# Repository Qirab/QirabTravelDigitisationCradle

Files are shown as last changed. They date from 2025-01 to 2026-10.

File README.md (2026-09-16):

#حامل «قِراب» المتنقل للرقمنة - QTC50
# Qirab Travel Digitisation Cradle - QTC50

يعد حامل «قِراب» المتنقل للرقمنة تصميمًا مفتوح المصدر لرقمنة المخطوطات قادر على حمل كتاب بحجم A4 بالإضافة إلى كاميرا ووحدات الإضاءة بأمان أثناء التصوير المتنقل.

The Qirab™ Travel Digitsation Cradle QTC50 is an open-source manuscript digitisation design intended to safely hold an A4 sized book, camera, and lights during travel imaging.

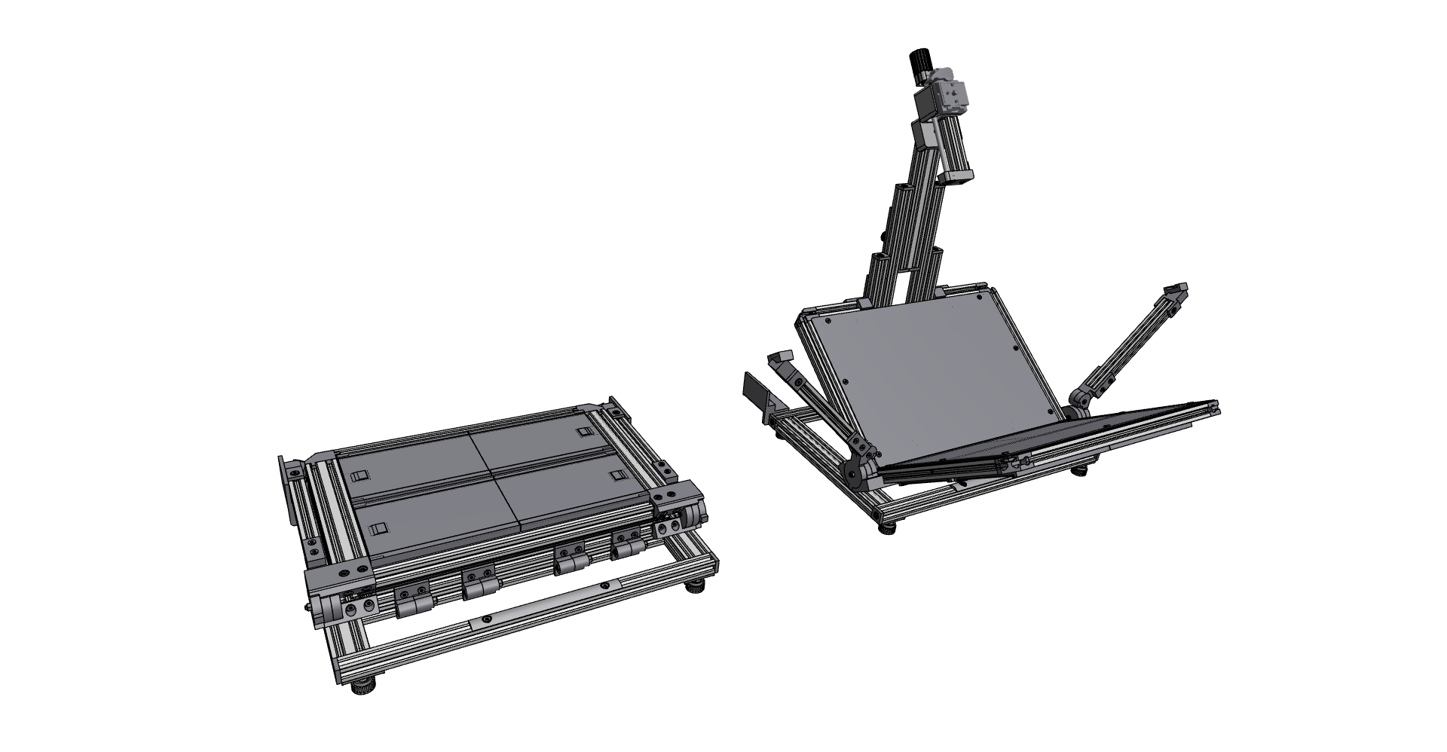
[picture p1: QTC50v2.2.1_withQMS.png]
QTC50v2.2.1_with QMS Macro Slider CAD

QTC50v2.2.1_with QMS Macro Slider CAD Drawing

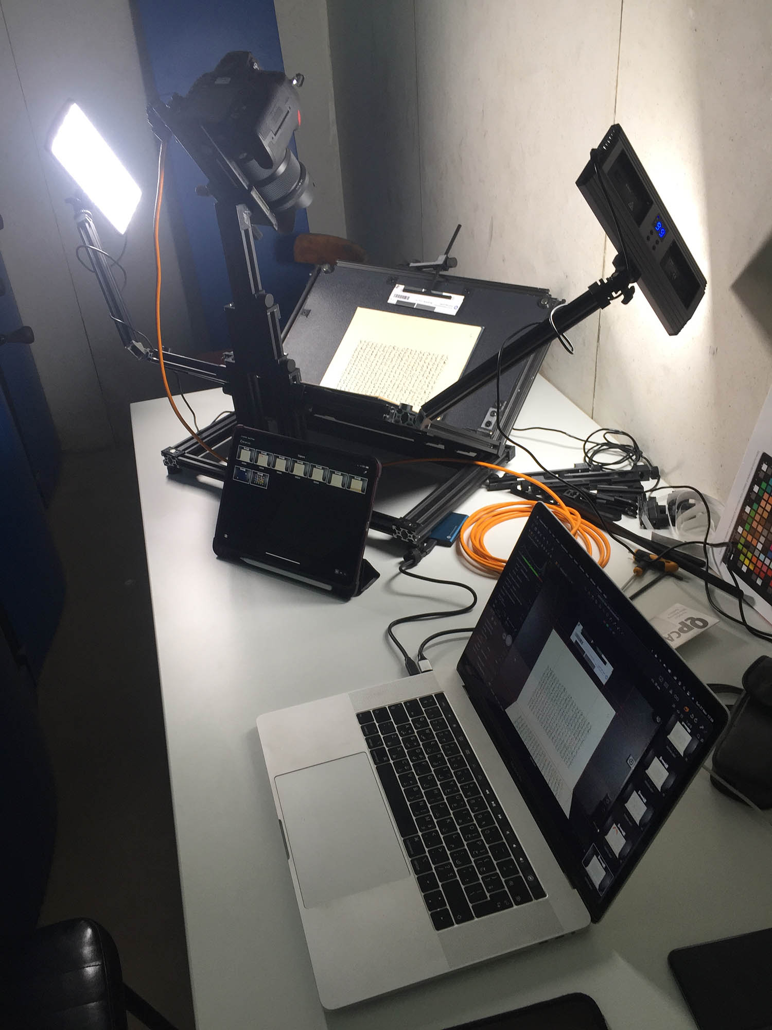
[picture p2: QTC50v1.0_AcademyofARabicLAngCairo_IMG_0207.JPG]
QTC50v1.0 Prototype testing at the Academy of Arabic Languagein Cairo, Egypt

QTC50v1.0 Prototype testing at the <a href="https://qirab.org/en/blog/2023/12/01/the-academys-manuscripts-preservation-and-digitisation/">Academy of Arabic Language in Cairo, Egypt</a>.

Requires <a href="https://github.com/Qirab/QirabTools">Qirab Tools</a> submodule.

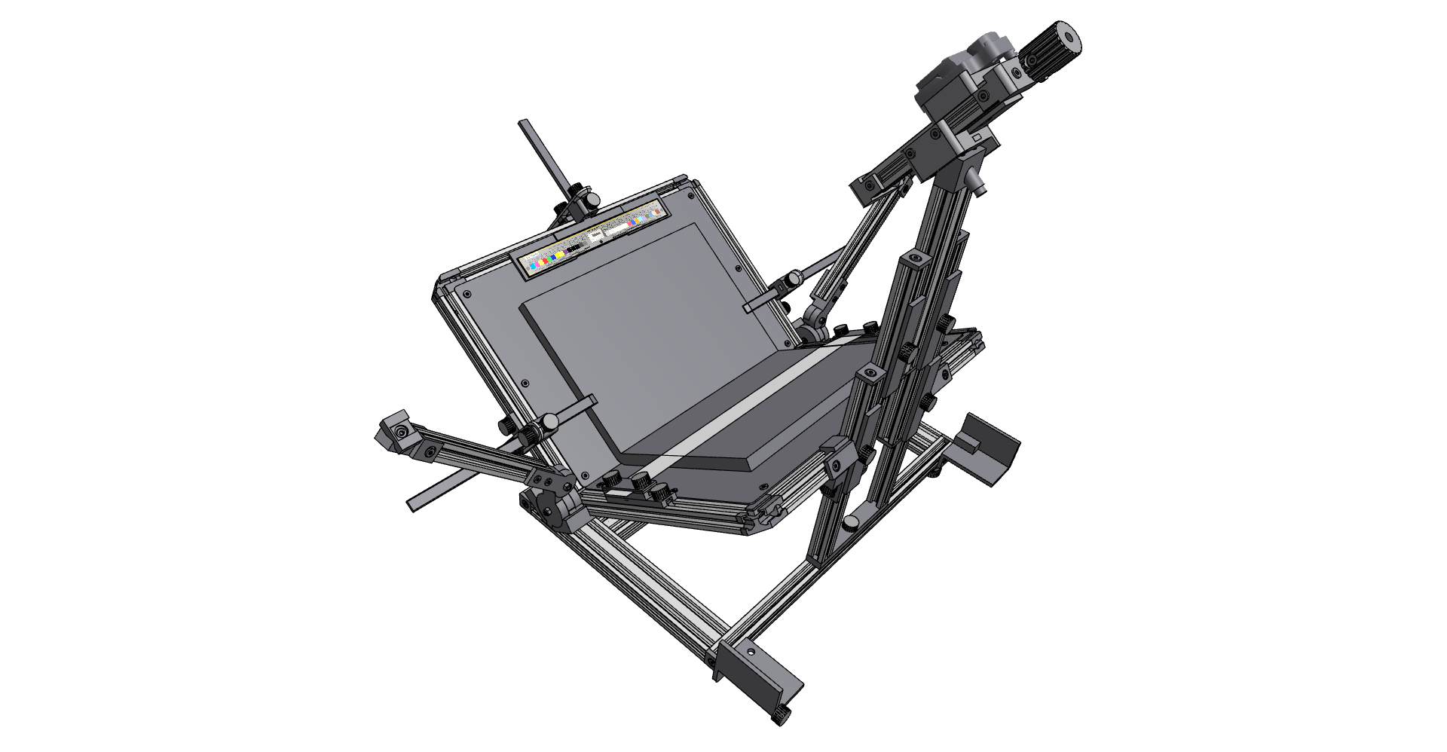
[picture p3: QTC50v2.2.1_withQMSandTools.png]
QTC50v2.2.1_with QMS Macro Slider and Qirab Tools CAD

QTC50v2.2.1_with QMS Macro Slider and Qirab Tools

<a href="https://github.com/Qirab/QirabMacroSlider">Qirab™ Macro Slider (QMS)</a> is optional.

<br />This work is licensed under a <a rel="license" href="http://creativecommons.org/licenses/by-sa/4.0/">Creative Commons Attribution-ShareAlike 4.0 International License</a>.

<br />هذا المُصنَّف مرخص بموجب <a rel="license" href="http://creativecommons.org/licenses/by-sa/4.0/">رخصة المشاع الإبداعي نَسب المُصنَّف - الترخيص بالمثل 4.0 دولي</a>.

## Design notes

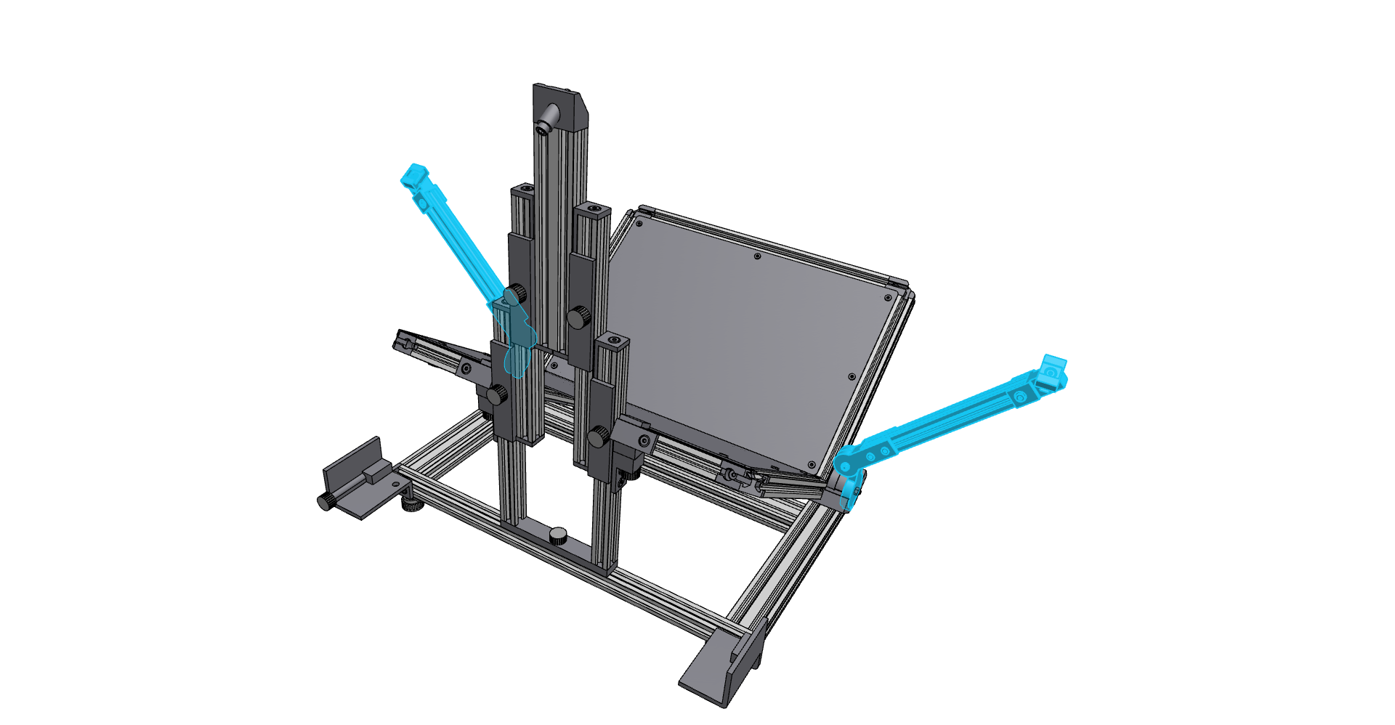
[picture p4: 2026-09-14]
PDF/Group Images/QTCv2.2.1_LightArms.png

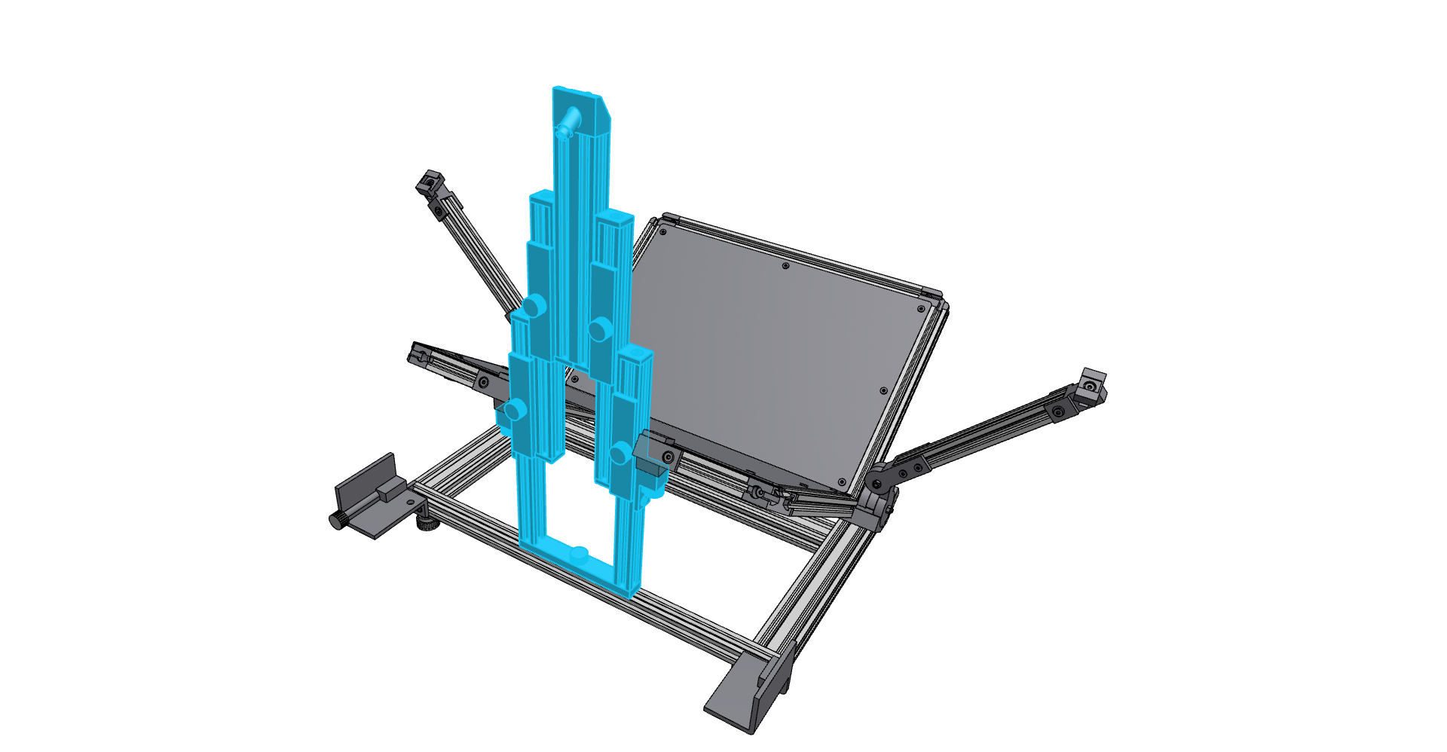
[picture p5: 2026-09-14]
PDF/Group Images/QTCv2.2.1_CameraArmSupport.png

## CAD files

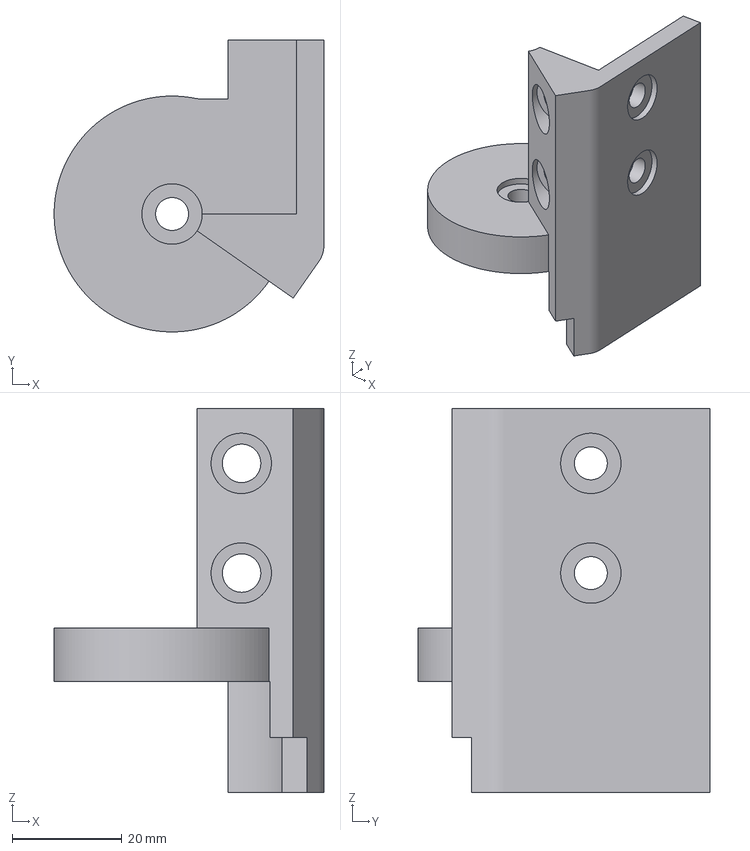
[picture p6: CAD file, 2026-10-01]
3DPRINT/1 EACH/QTC Frame Hinge Inner R.3mf
49.2 x 53.2 x 70.0 mm

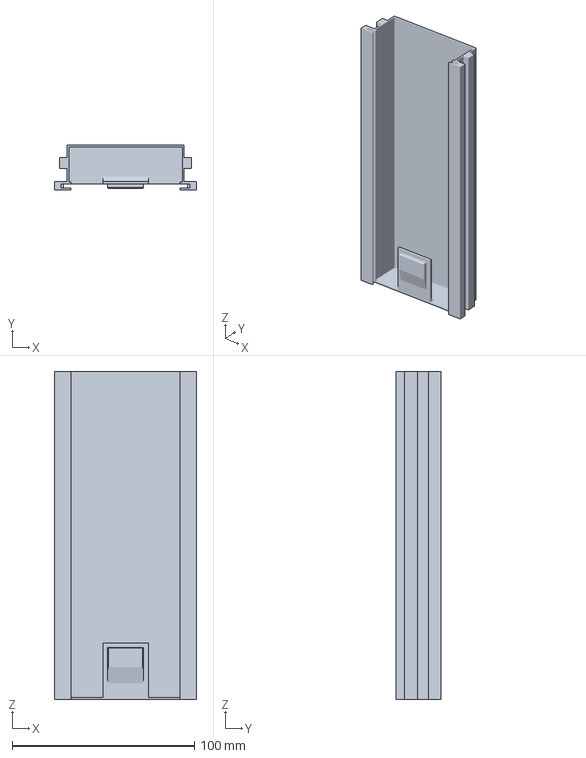
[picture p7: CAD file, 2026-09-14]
3DPRINT/2 EACH/QTC Box Small QTC50.3mf
78.0 x 24.7 x 180.0 mm

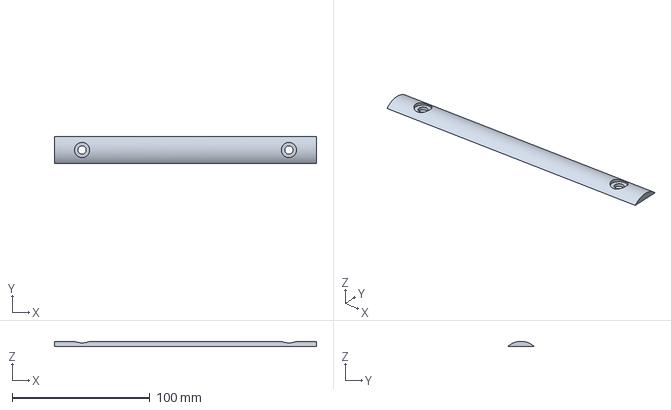
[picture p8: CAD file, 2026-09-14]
3DPRINT/3 EACH/QTC Handle Curve.3mf
190.0 x 19.3 x 3.90 mm

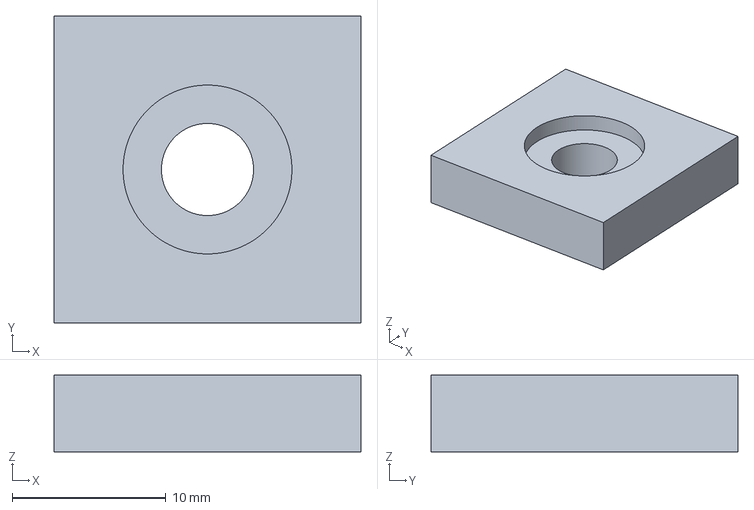
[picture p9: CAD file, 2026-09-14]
3DPRINT/4 EACH/QTC Endcap 20x20x5.3mf
20.0 x 20.0 x 5.00 mm

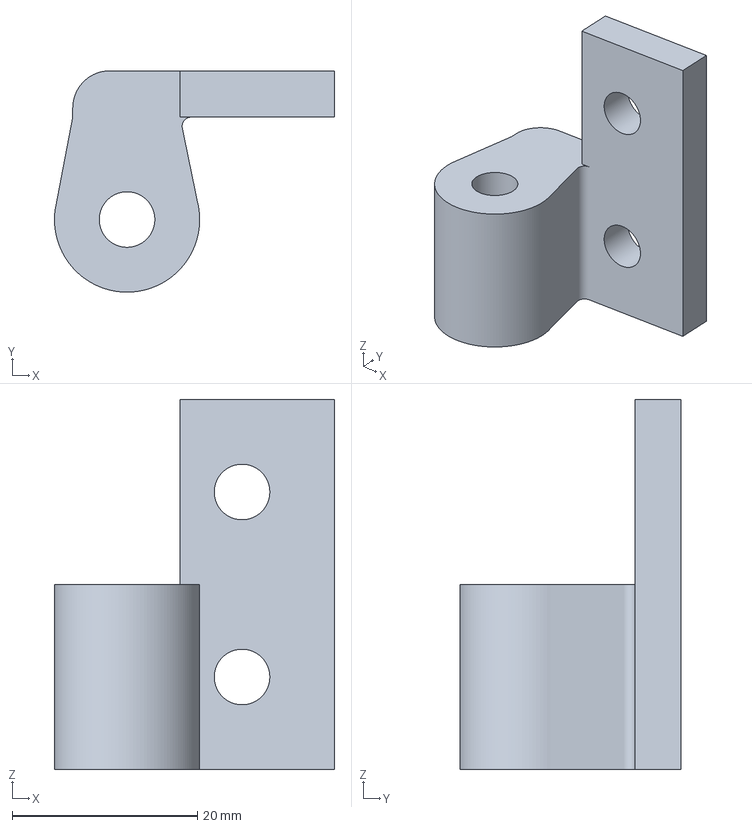
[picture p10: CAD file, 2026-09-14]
3DPRINT/8 EACH/QTC Base Hinge.3mf
30.3 x 23.9 x 40.0 mm

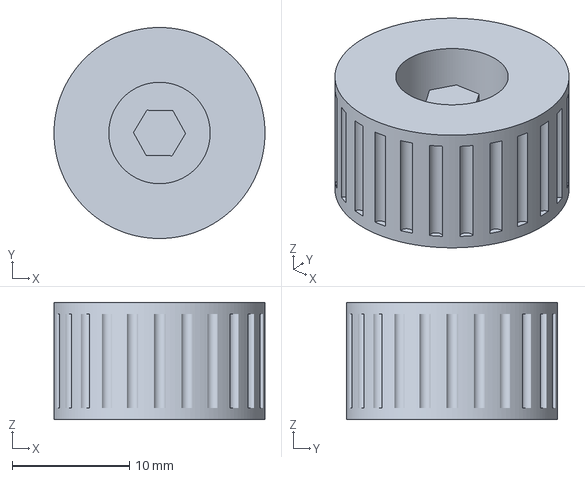
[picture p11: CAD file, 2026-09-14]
3DPRINT/9 EACH/M5 Tool Knob.3mf
18.0 x 18.0 x 10.0 mm

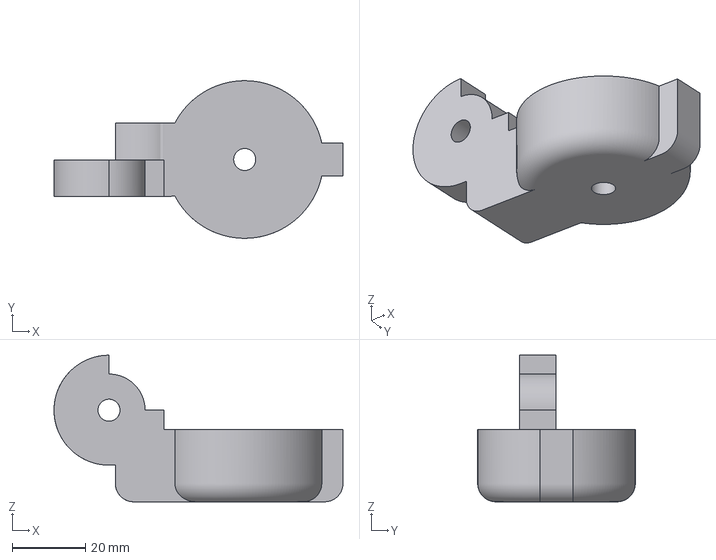
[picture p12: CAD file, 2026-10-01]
3DPRINT/1 EACH/QTC 20mm Frame Hinge Outer L.3mf
78.8 x 43.0 x 40.0 mm

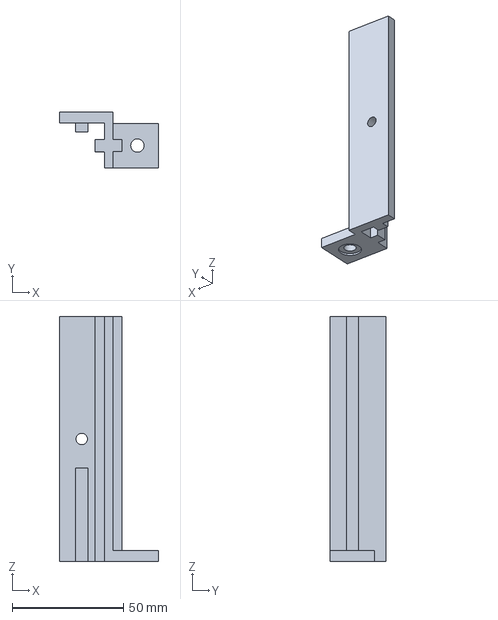
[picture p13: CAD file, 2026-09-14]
3DPRINT/2 EACH/QTC CamArm Slider Lock R.3mf
44.5 x 25.0 x 110.0 mm

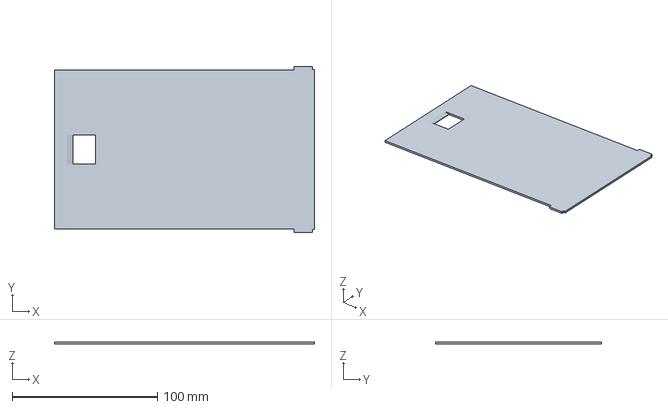
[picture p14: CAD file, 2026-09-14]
3DPRINT/4 EACH/QTC Box Lid QTC50.3mf
179.0 x 114.2 x 1.50 mm

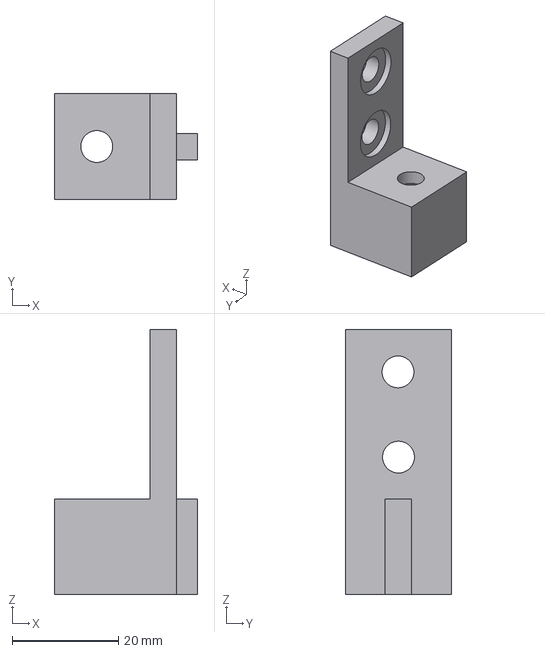
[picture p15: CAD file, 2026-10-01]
3DPRINT/1 EACH/QTC CamArm Lock Lower.3mf
27.0 x 20.0 x 50.0 mm

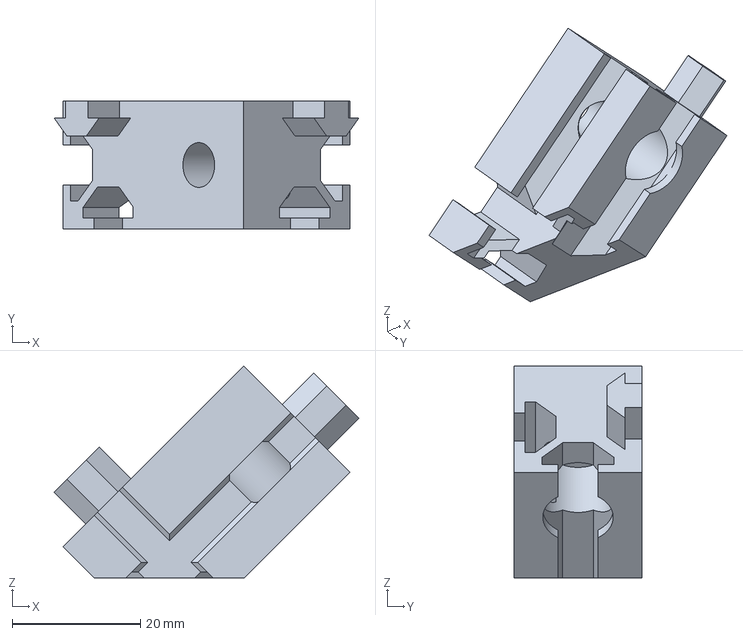
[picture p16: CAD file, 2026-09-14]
3DPRINT/2 EACH/QTC Corner 40 R.3mf
47.7 x 20.0 x 33.1 mm

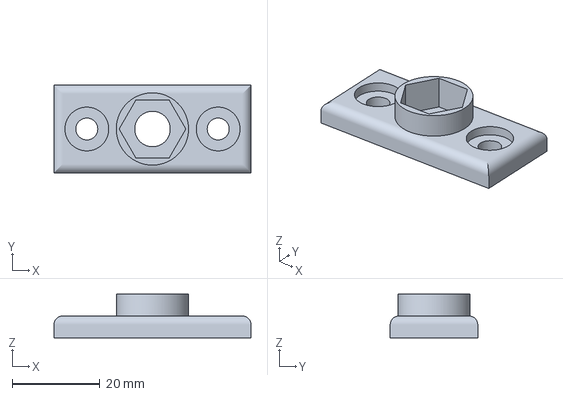
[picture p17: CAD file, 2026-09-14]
3DPRINT/4 EACH/QTC Foot Bracket.3mf
45.0 x 20.0 x 10.0 mm

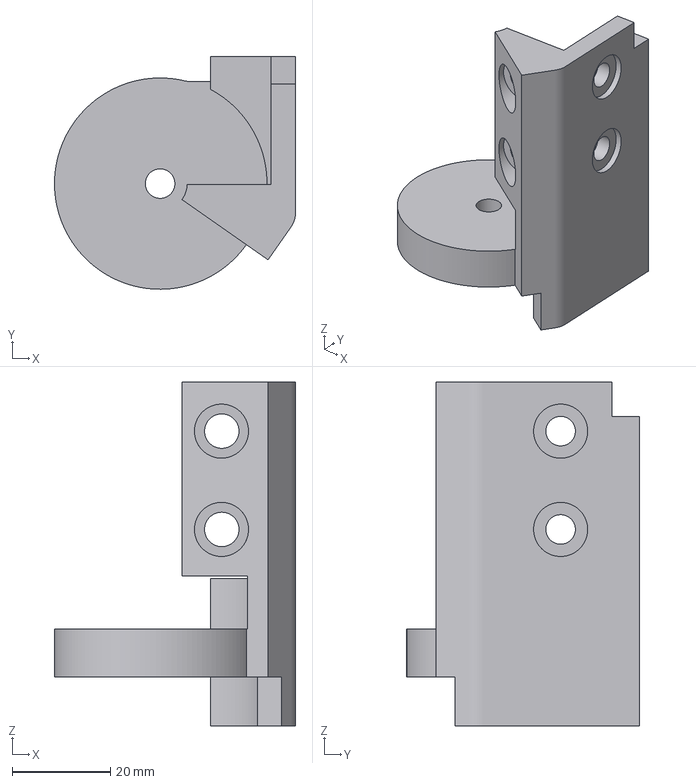
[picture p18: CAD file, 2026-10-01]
3DPRINT/1 EACH/QTC Frame Hinge Middle L.3mf
49.0 x 47.3 x 70.0 mm

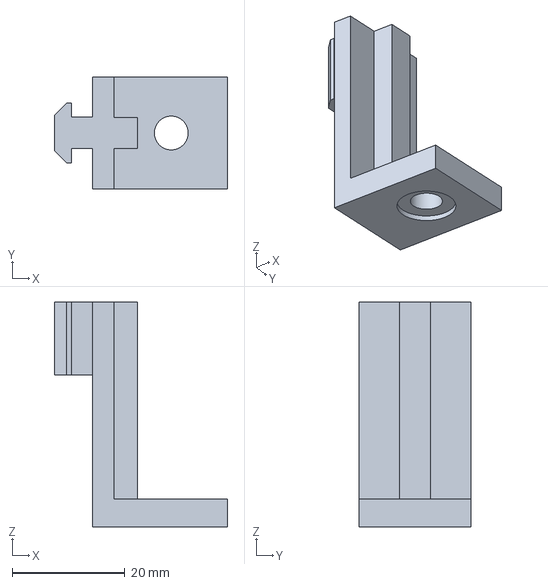
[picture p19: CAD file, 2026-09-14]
3DPRINT/2 EACH/QTC CamArm Slider Short.3mf
30.8 x 20.0 x 40.0 mm

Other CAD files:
3DPRINT/4 EACH/QTC Foot.3mf
3DPRINT/1 EACH/QTC CamArm Lock Lower 2.3mf
3DPRINT/2 EACH/QTC CamArm Slider Lock L.3mf
3DPRINT/4 EACH/QTC Box QTC50.3mf
3DPRINT/1 EACH/QTC 20mm Frame Hinge Outer R.3mf
3DPRINT/1 EACH/QTC 20mmNOTCH Frame Hinge Outer L.3mf
3DPRINT/1 EACH/QTC 20mmNOTCH Frame Hinge Outer R.3mf
3DPRINT/1 EACH/QTC Cam Block.3mf
3DPRINT/1 EACH/QTC CamArm Base.3mf
3DPRINT/1 EACH/QTC CamArm Upper Lock L.3mf
3DPRINT/1 EACH/QTC CamArm Upper Lock R.3mf
3DPRINT/1 EACH/QTC Camera Arm Retaining Ring.3mf
3DPRINT/1 EACH/QTC Frame Hinge Inner L.3mf
3DPRINT/1 EACH/QTC Frame Hinge Middle R.3mf
3DPRINT/1 EACH/QTC Frame Hinge Outer LEFT.3mf
3DPRINT/1 EACH/QTC Frame Hinge Outer RIGHT.3mf
3DPRINT/1 EACH/QTC Imaging Board.3mf
3DPRINT/1 EACH/QTC Light Arm Hinge LEFT EXPERIMENTAL.3mf
3DPRINT/1 EACH/QTC Light Arm Hinge RIGHT EXPERIMENTAL.3mf
3DPRINT/1 EACH/QTC Light Arm Top LEFT.3mf
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

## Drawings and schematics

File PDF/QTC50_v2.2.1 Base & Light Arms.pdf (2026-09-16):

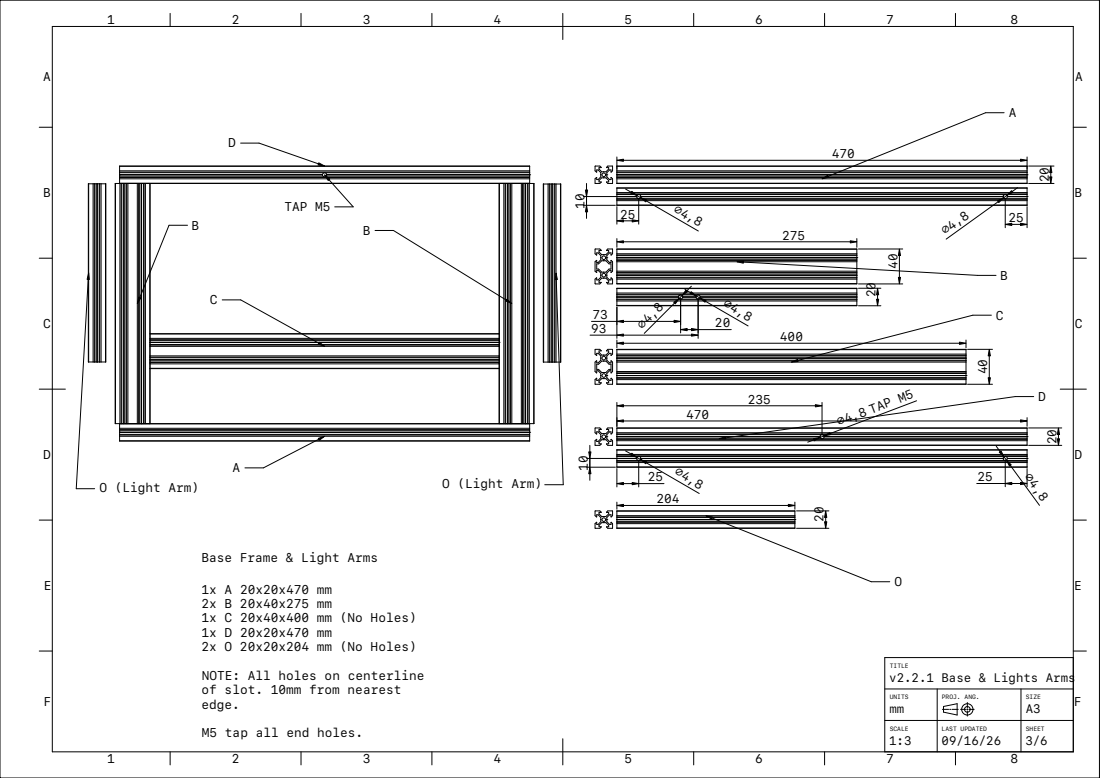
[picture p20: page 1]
4,8TAP M5; O (Light Arm); TAP M5

Base Frame & Light Arms
1x C 20x40x400 mm (No Holes)
2x O 20x20x204 mm (No Holes)
NOTE: All holes on centerline
of slot. 10mm from nearest
edge.
M5 tap all end holes.

TITLE
v2.2.1 Base & Lights Arms

UNITS mm | PROJ. ANG. | SIZE A3

SCALE 1:3 | LAST UPDATED 09/16/26 | SHEET 3/6

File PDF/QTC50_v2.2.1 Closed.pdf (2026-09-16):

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

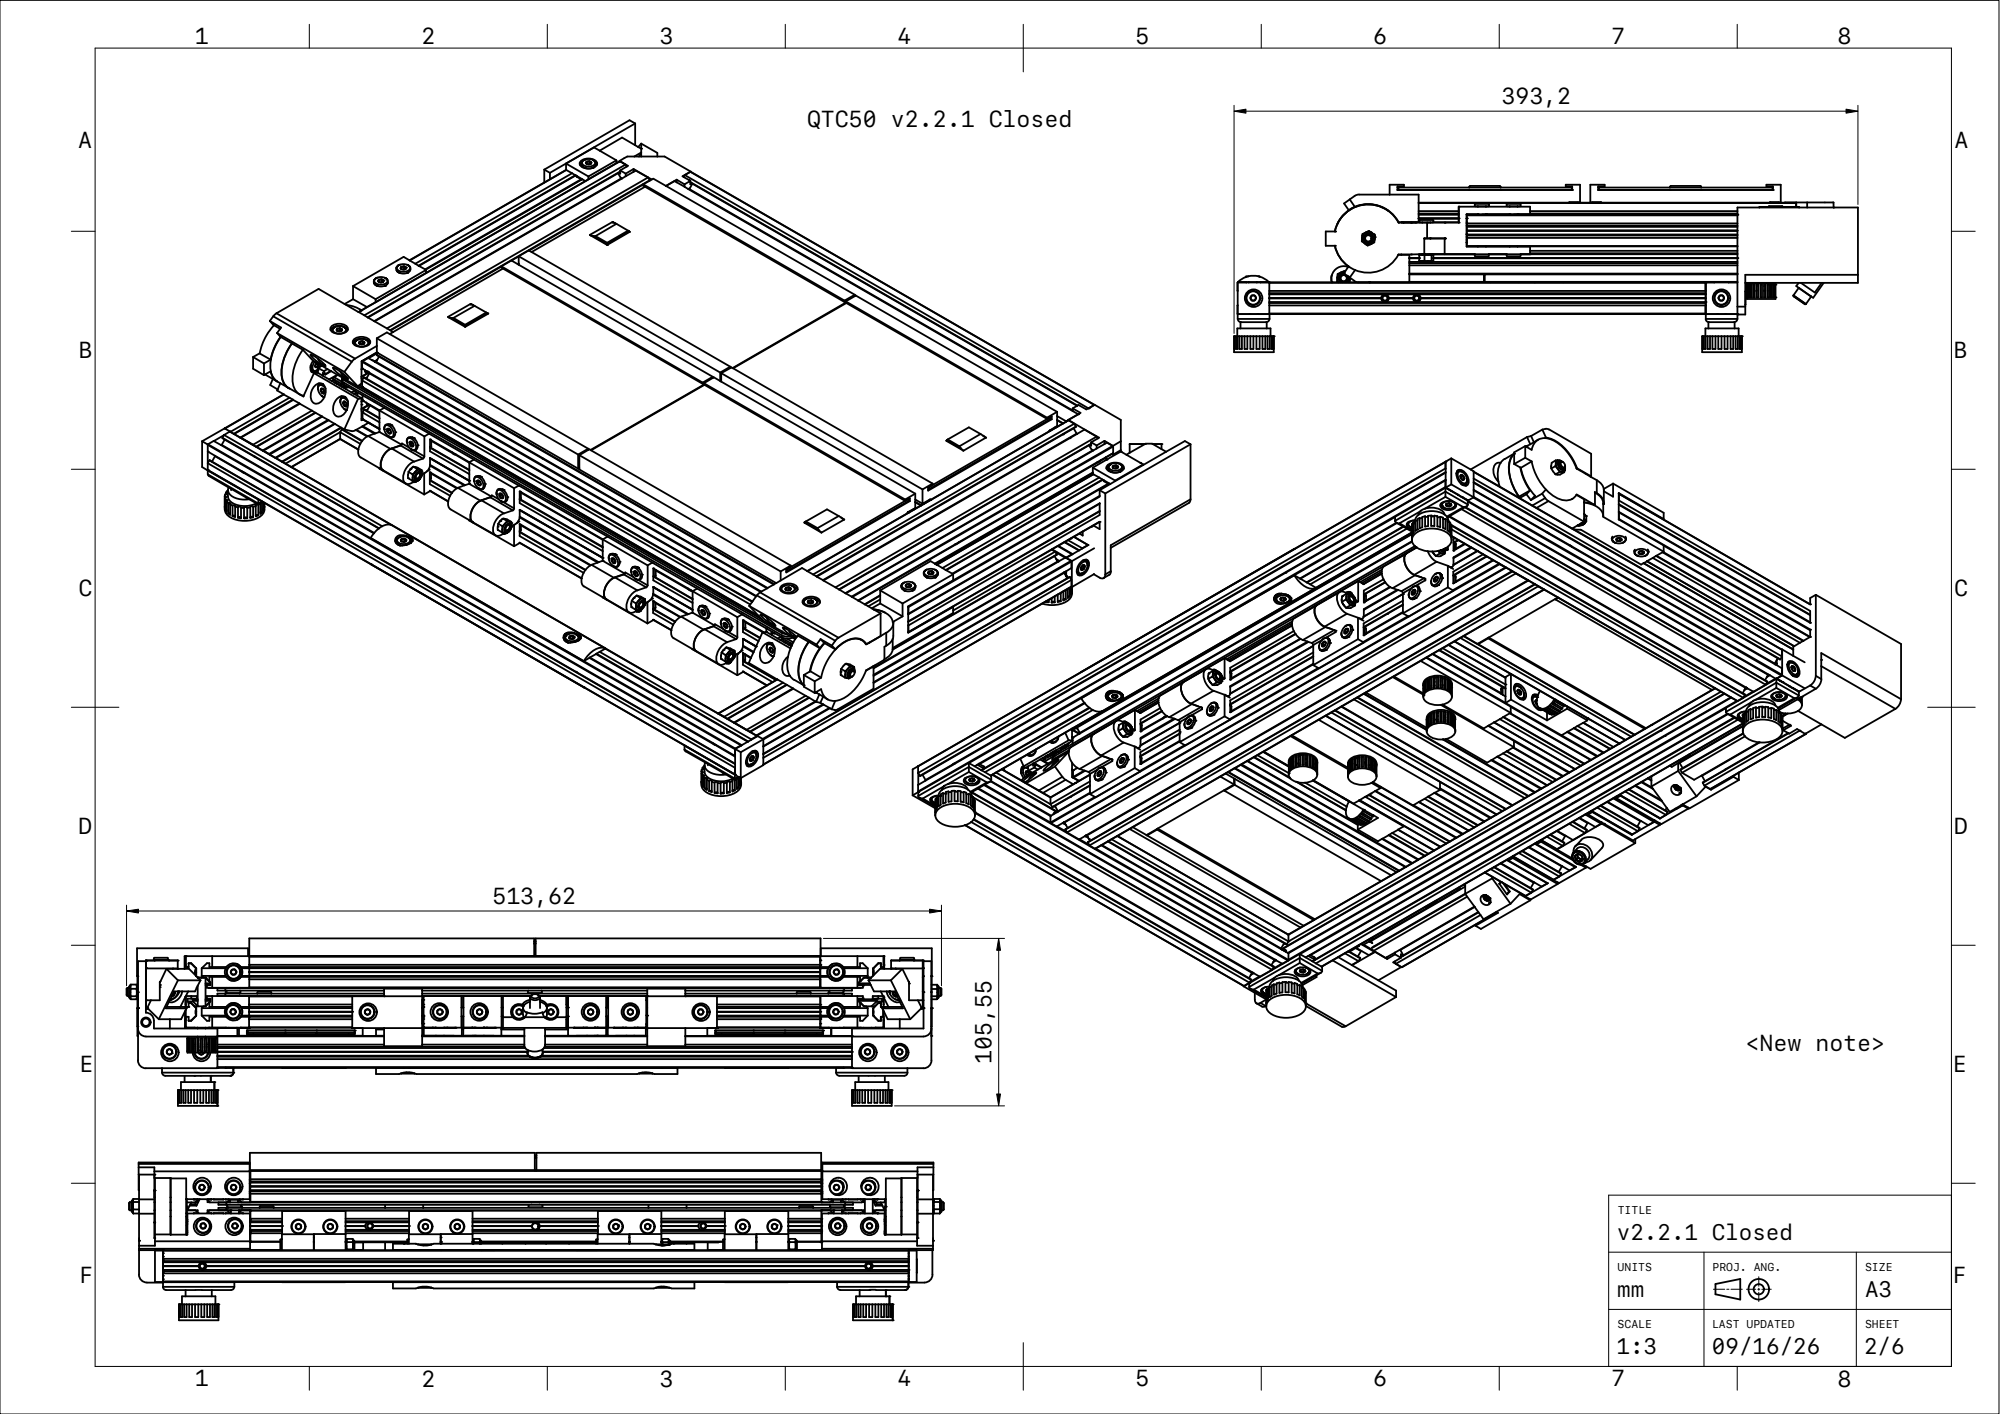
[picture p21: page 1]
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

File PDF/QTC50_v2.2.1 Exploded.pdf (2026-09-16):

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

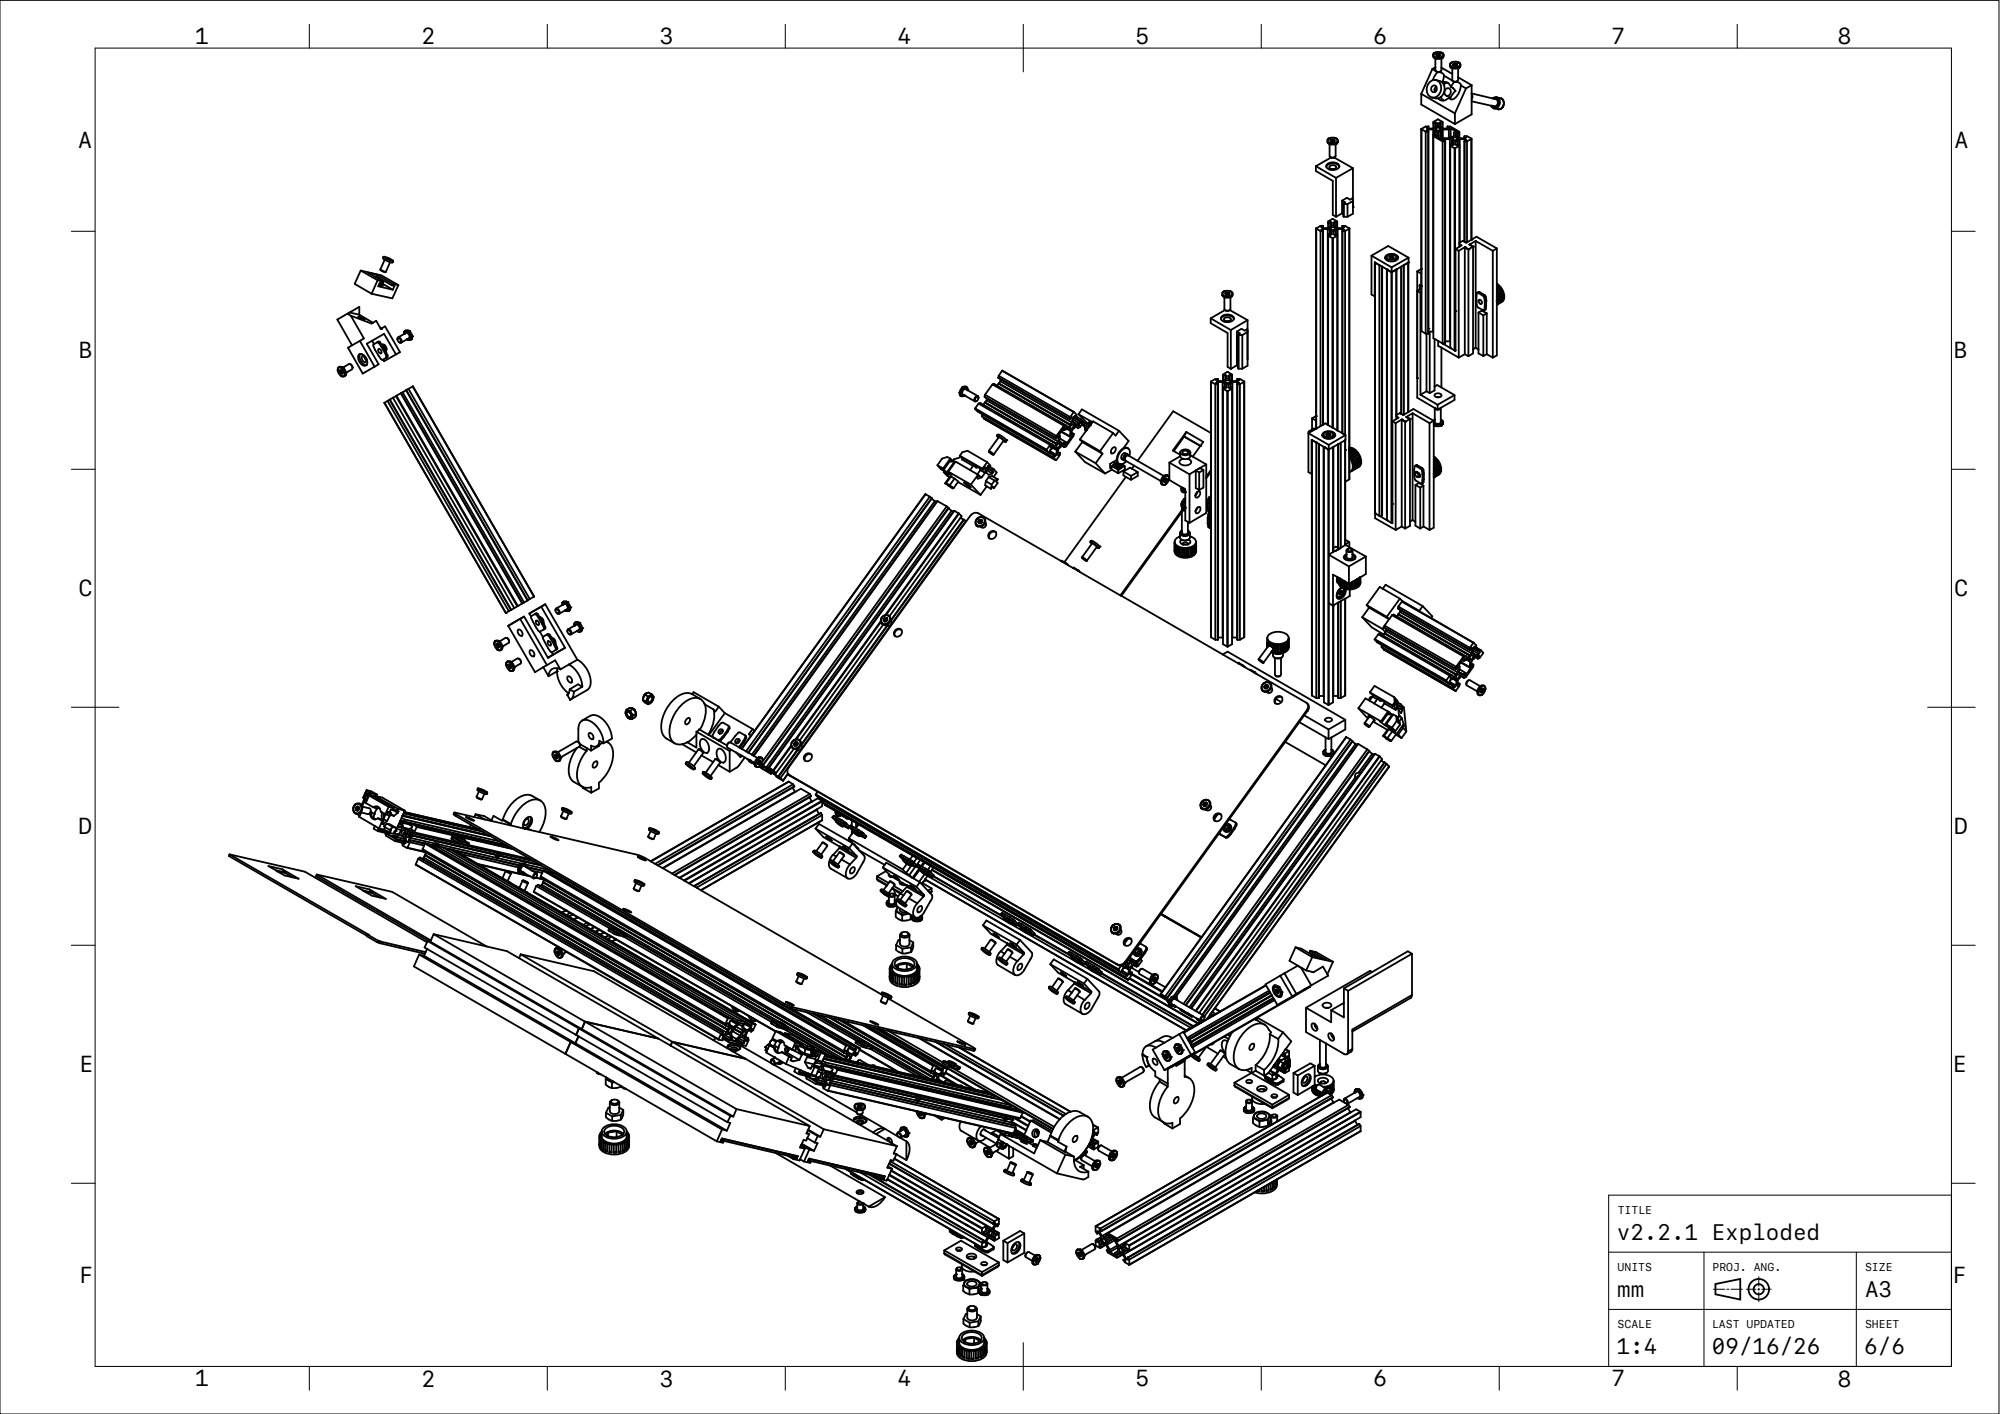
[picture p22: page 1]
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

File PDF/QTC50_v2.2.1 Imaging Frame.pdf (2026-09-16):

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

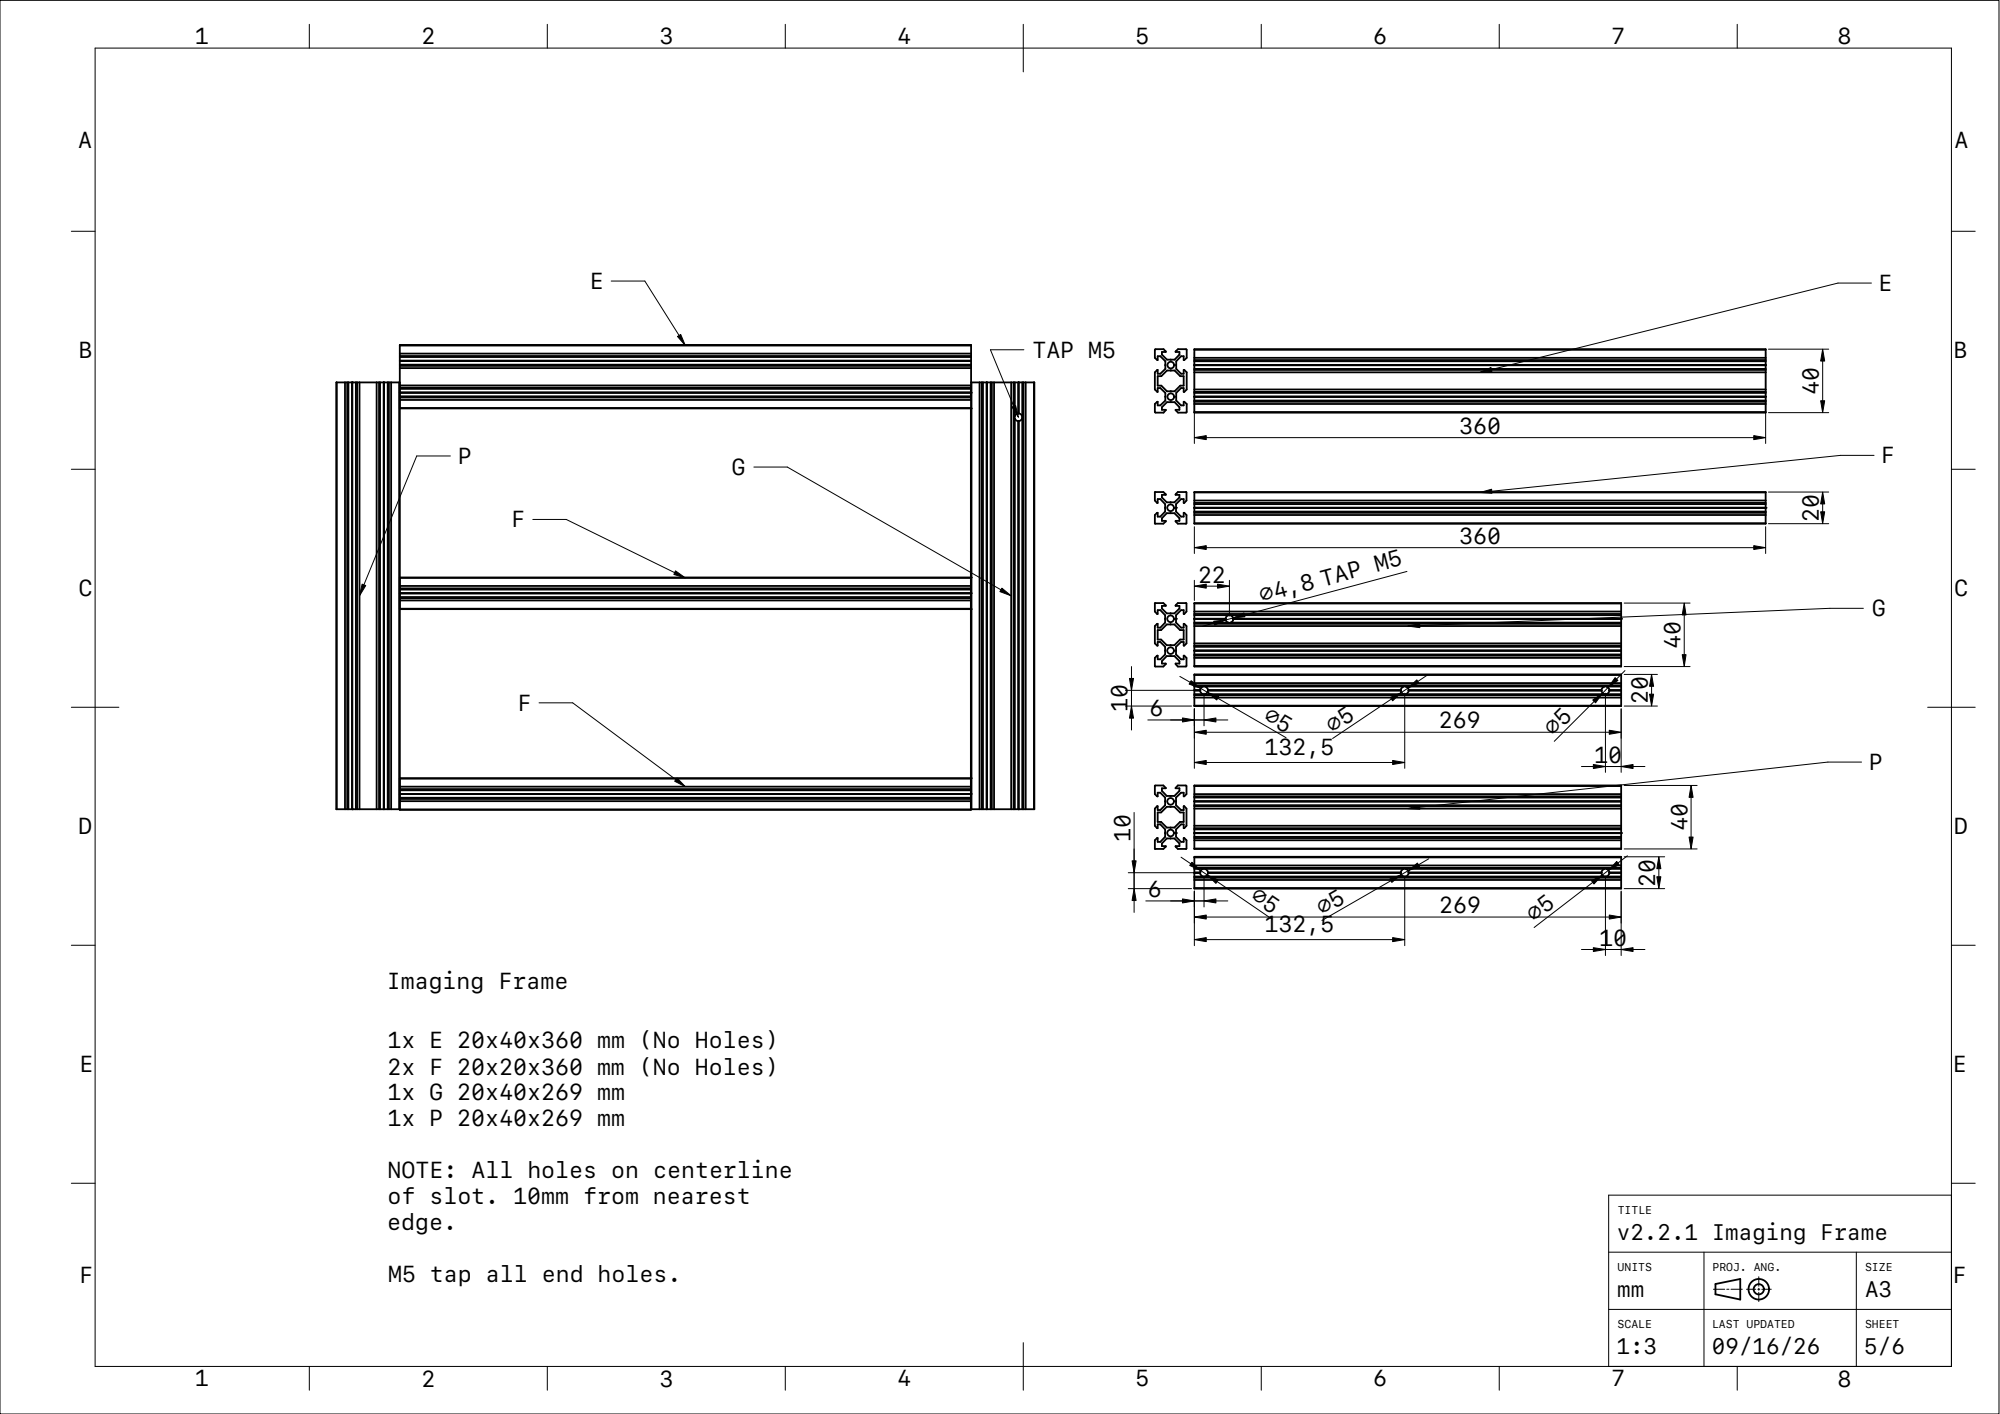
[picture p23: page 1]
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

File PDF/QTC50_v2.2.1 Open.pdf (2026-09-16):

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

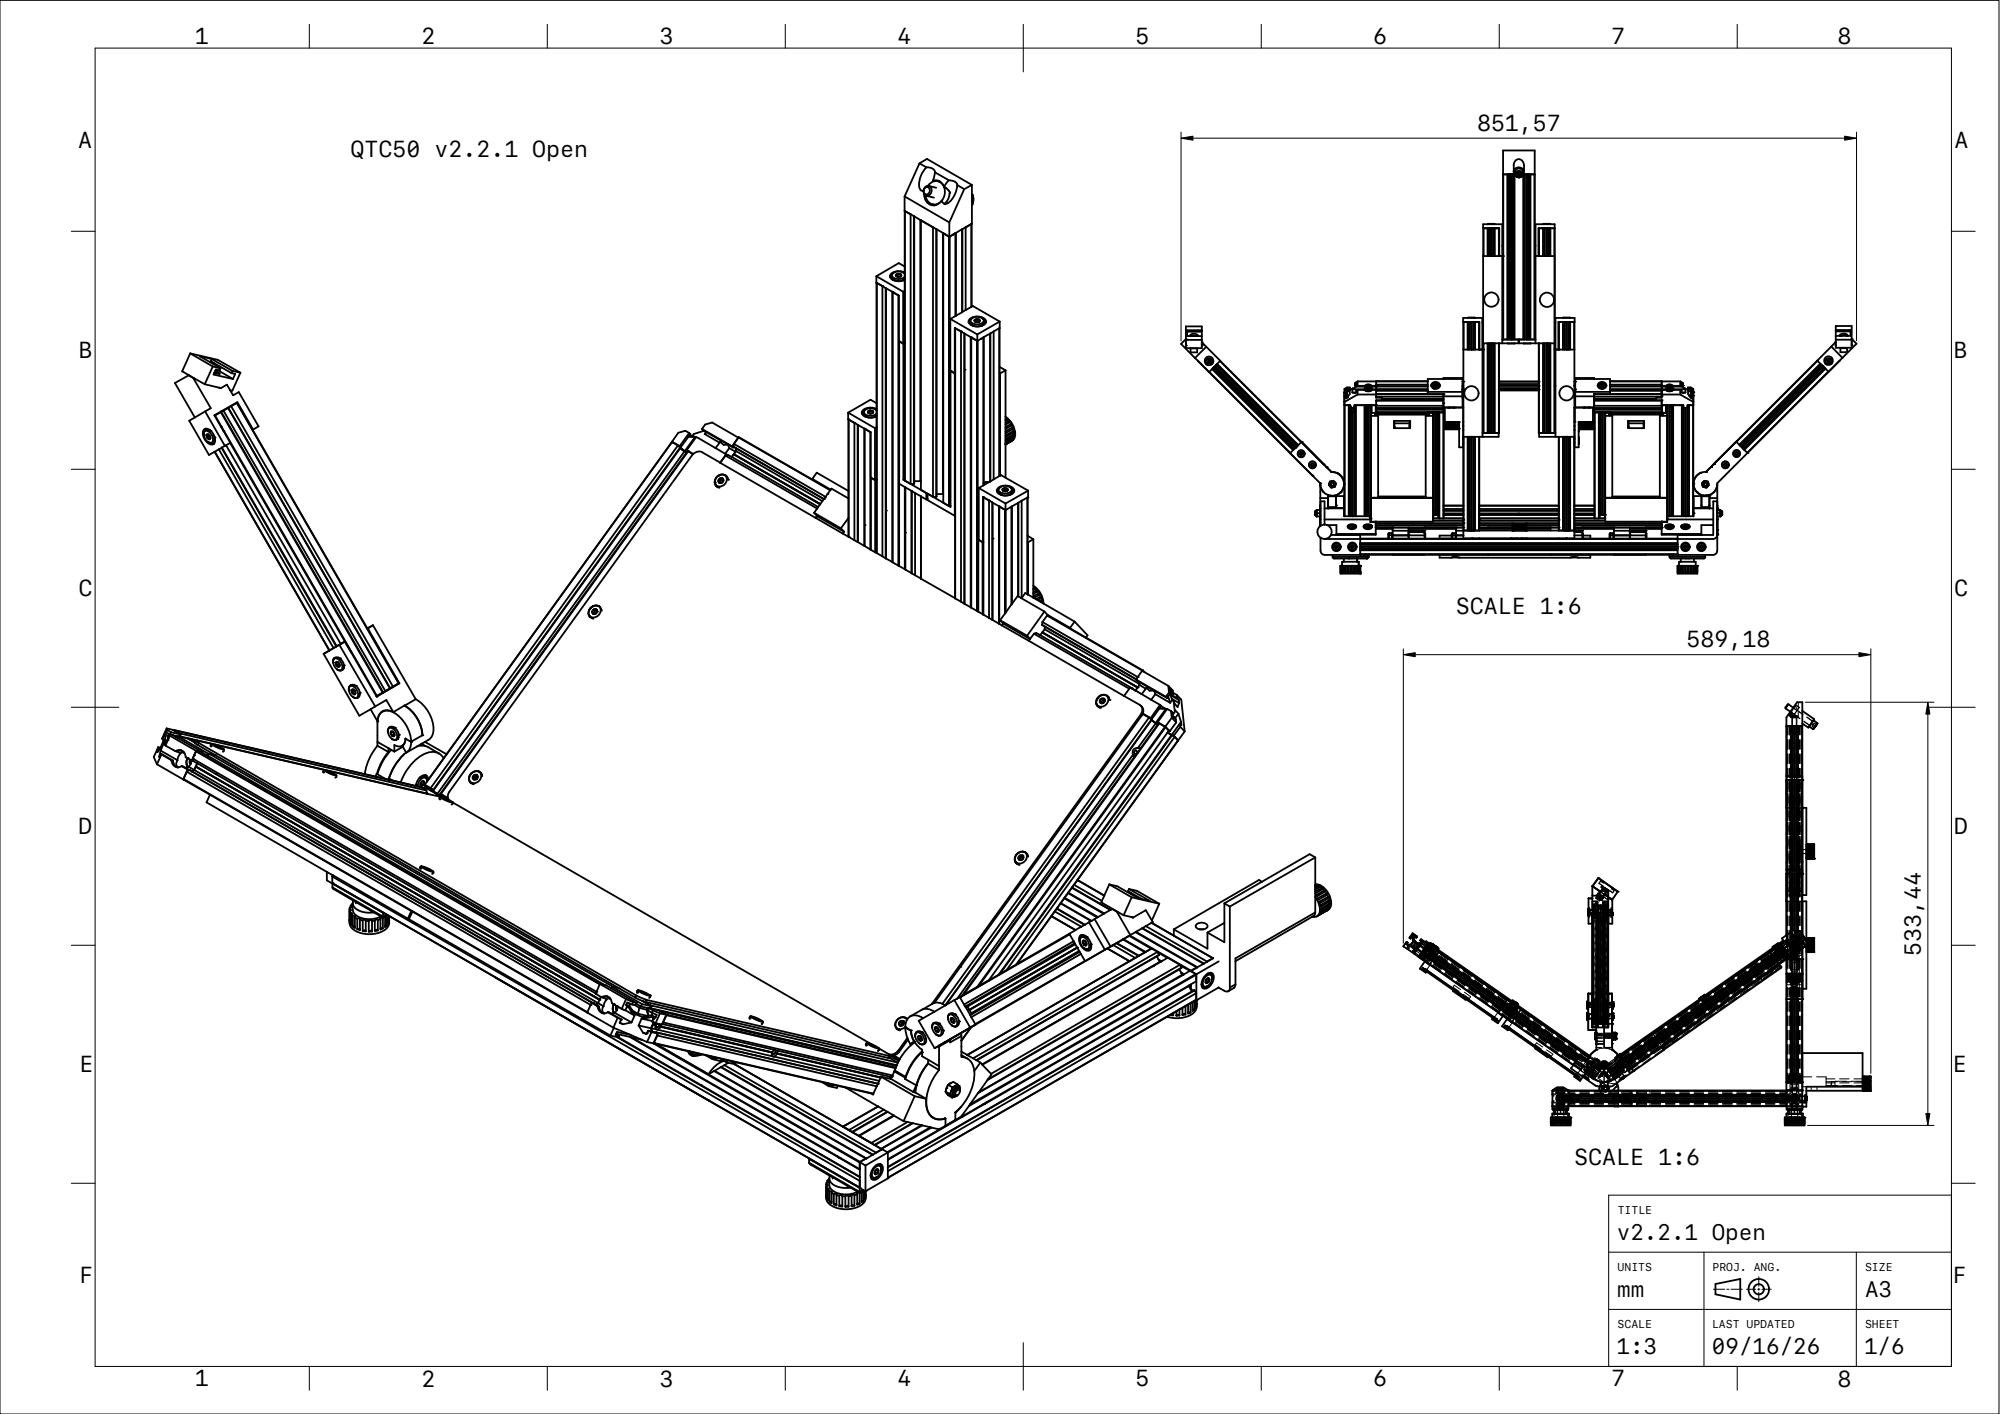
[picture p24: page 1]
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

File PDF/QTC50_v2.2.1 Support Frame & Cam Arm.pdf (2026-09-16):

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

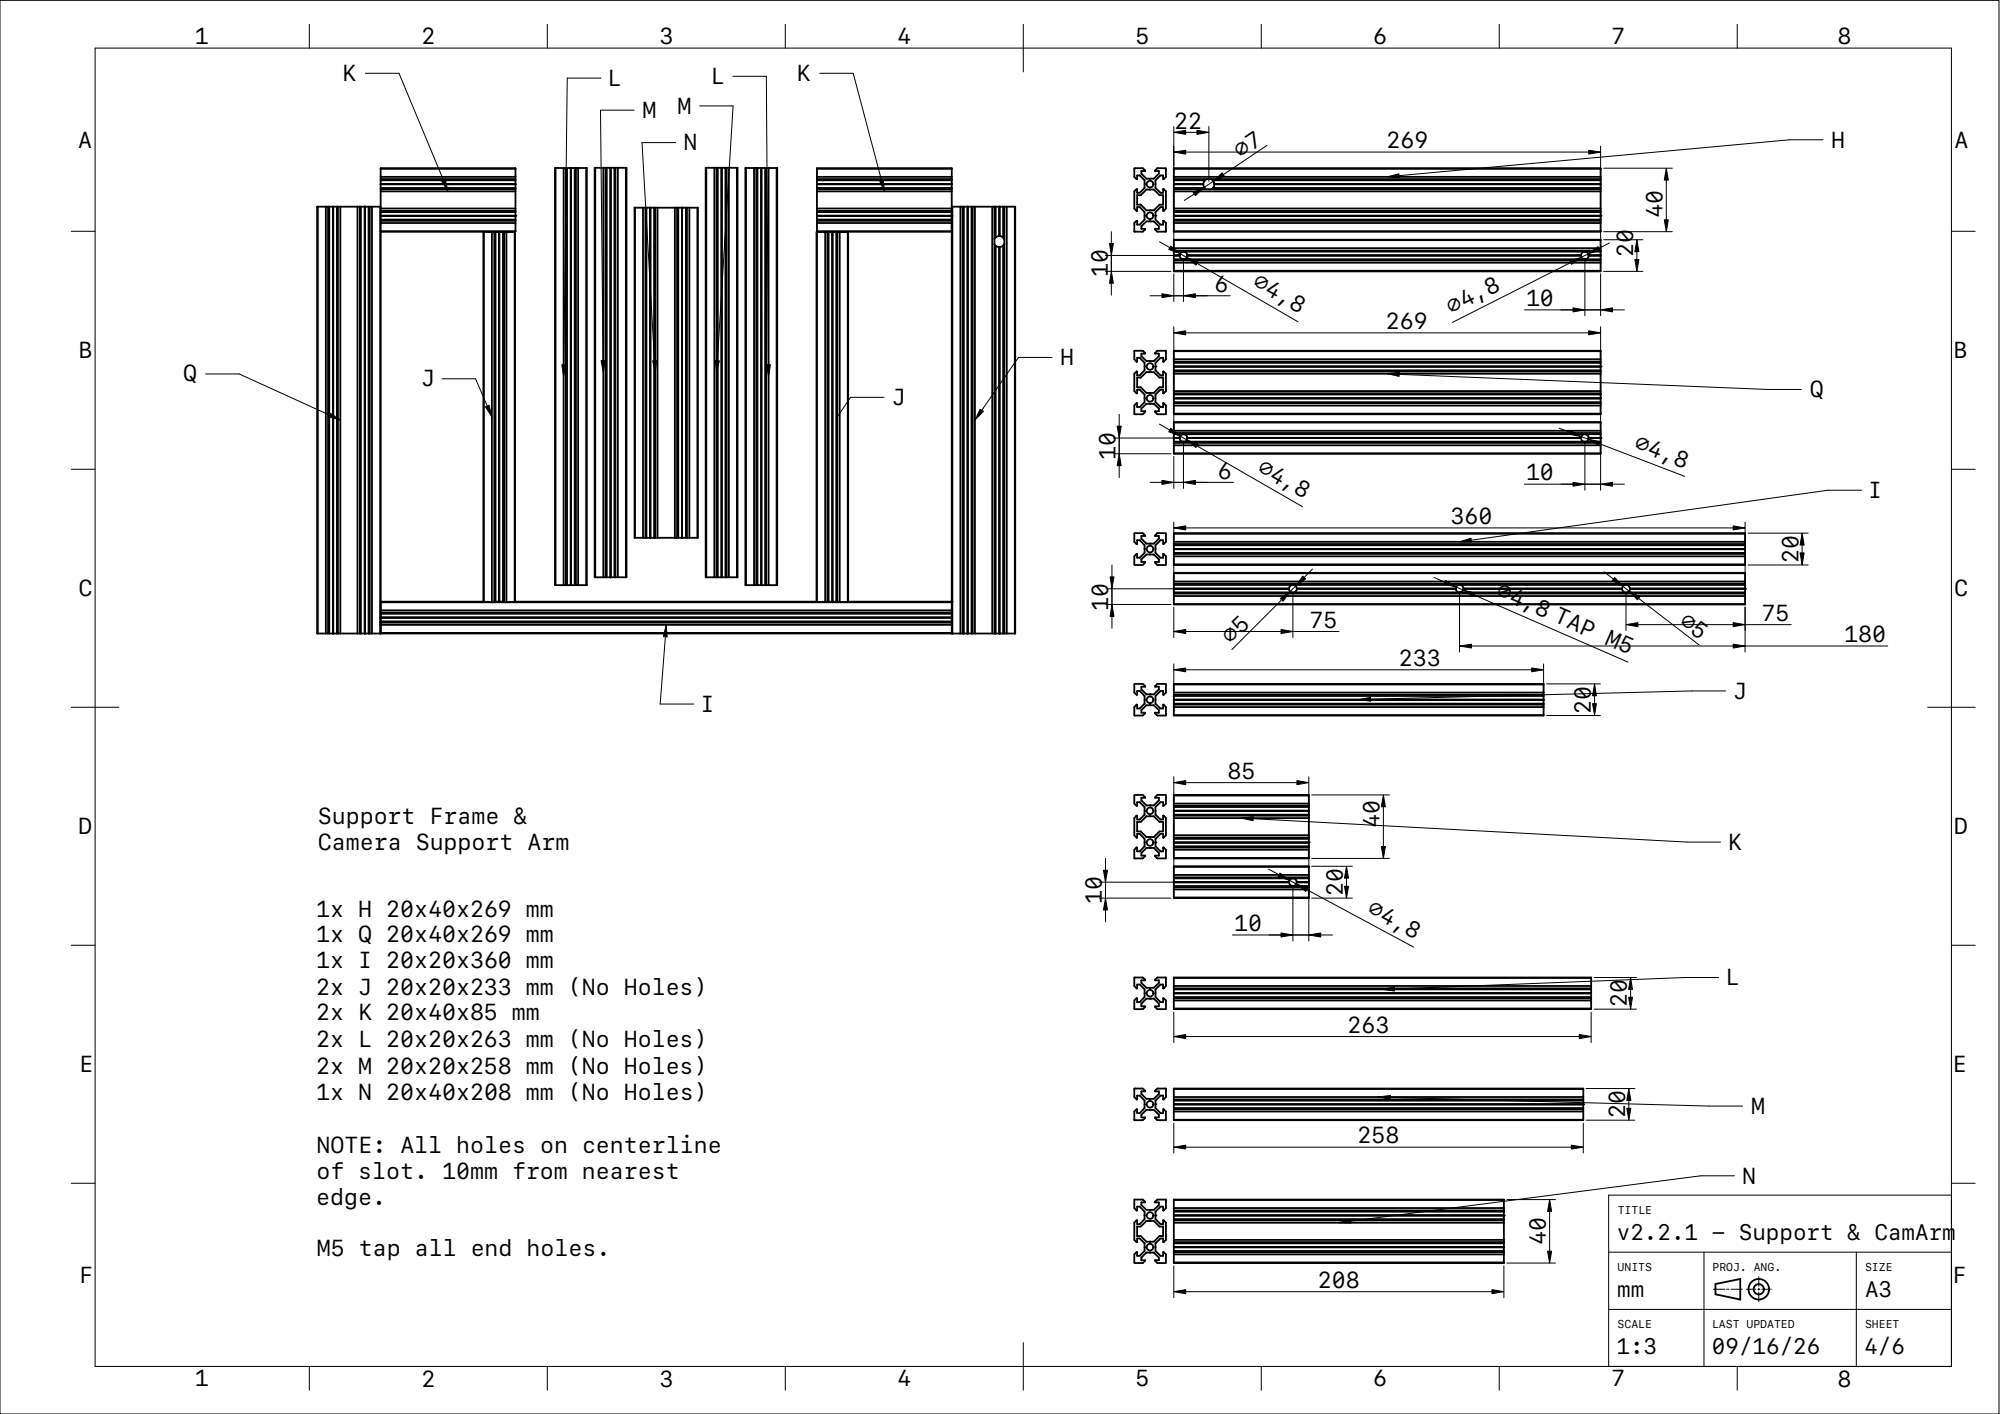
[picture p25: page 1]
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

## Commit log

2025-09-22 exported 3FM for printing and made PDFs for Alum cut
    [Base Hinge (1).3mf, CamArm Base (1).3mf, CamArm Base Retaining Washer (1).3mf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]
2025-09-23 fixed PDF typos
    [QTC v2 Hardware BOM.xlsx]
2025-10-21 3D Print part count fix
    [CamArm Slider Short.3mf, CamArm Slider.3mf, Camera Arm Retaining Ring (5).3mf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]
2025-11-02 v2.1 upload
    [Base Hinge (1).3mf, Base Hinge.3mf, Box Lid QTC50.3mf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]
2025-11-02 updated step and BOM
    [QTC v2 Hardware BOM.xlsx, QTC v2.1 Hardware BOM.xlsx]
2025-11-02 added images of frame groups highlighted
2025-11-02 added plug for camera arm lock
    [CamArm Upper Lock Plug.3mf]
2025-11-04 exported boards with 7.5 mm holes for print
    [Imaging Board.3mf, Support Board.3mf]
2025-11-04 updated boards and corners
    - Widened board holes to 7.5 and rounded corneres fro faster printing
    - Added hole and 15mm screw to corner blocks
    - Updated BOM XLS File
    [Corner 40 L.3mf, Corner 40 R.3mf, QTC v2.1 Hardware BOM.xlsx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]
2025-11-06 added missing part
    [CamArm Slider Lock R.3mf]
2025-11-06 added yellow highlights to holes in PDF needing tapping
2026-09-14 adding files to prepare for 2.2.1 release
    [Base Hinge.3mf, Box Lid QTC50.3mf, Box QTC50.3mf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]
2026-09-14 added v2.2.1 group highlight screenshots to CAD dir
2026-09-14 updated Bill of Materials and added new cad photo
    [QTC v2.1.1 Hardware BOM.xlsx, QTC v2.2.1 Hardware BOM.xlsx]
2026-09-24 renamed 3mf files with QTC prefix
    [QTC Base Hinge.3mf, QTC Box Lid QTC50.3mf, QTC Box QTC50.3mf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]
2026-10-01 3mf upload
    - added missing lower camarm lock
    - adjusted inner and middle hinge for printing
    - added 20mm thick outer hinge for testing
    [QTC 20mm Frame Hinge Outer L.3mf, QTC 20mm Frame Hinge Outer R.3mf, QTC 20mmNOTCH Frame Hinge Outer L.3mf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]

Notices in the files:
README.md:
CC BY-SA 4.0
